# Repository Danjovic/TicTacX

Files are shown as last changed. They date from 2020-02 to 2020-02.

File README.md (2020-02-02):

# Tic Tac X

Tic Tac X is a portable color bar genarator designed to be provide the identification of VGA monitors that are able to operate with RS-170 (RGB 15.75KHz hsync).
The signals generated mimics the timing of syncrhonization pulses produced by TMS9128 (MSX1), V9938 (MSX2) and TK90X ULA (ZX Spectrum clone). A VGA mode is also provided to check the operational state of the monitor under native video signal. 

## Operation
The board provides a Jumper to turn on/off the board. As soon as the Jumper is inserted the board is powered and the VGA mode kicks in.

The board also provides a push button to change the signal mode. At every press it advances to the next mode until it returns to native (VGA) mode.

Those are the modes available:

1. VGA,  separated Hsync and Vsync 
2. NTSC, composite sync on Hsync pin
3. NTSC, separated Hsync and Vsync 
4. NTSC, sync on green
5. PAL,  composite sync on Hsync pin
6. PAL,  separated Hsync and Vsync 
7. PAL,  sync on green

All modes provide a colour bar pattern in the following sequence:

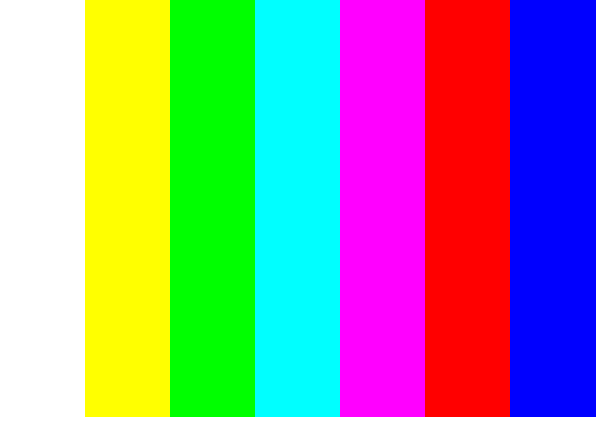
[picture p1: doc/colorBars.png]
Colour Bars


All modes, except VGA provide an horizontal bar atthe middle of the height of the screen that provides information about the mode being generated, type of synchronism signals and vertical frequency
 
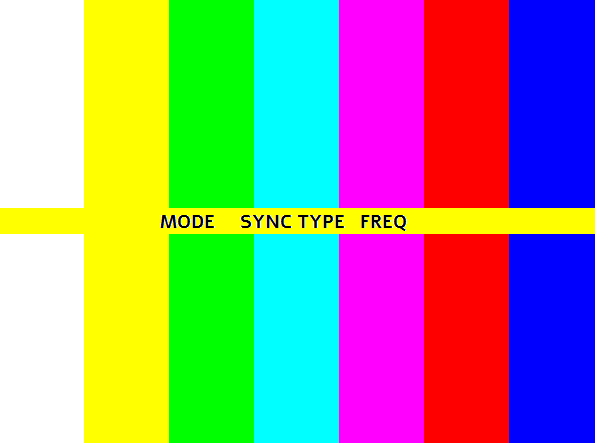
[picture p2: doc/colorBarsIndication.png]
Colour Bars and Indication


*Modes:*
* MSX1 - TMS9128 compatible, 262/313 lines progressive
* MSX2 - V9938 compatible, 525/625 lines interlaced
* TK90 - (ZX spectrum clone)

*Synchronism type:*
* CSy - Composite sync on Hsync line
* HV  - Separate Hsync and Vsync
* SoG - Sync on Green

The color of such bar relates to the type of synchronism signals
* Yellow: Composite sync
* White:  Separate Hsync
* Green:  Sync on Green

*Vertical frequency:*
* 60 - NTSC
* 50 - PAL

## Battery Saving
After 1 minute without any press of the button the board enters in sleep mode to save the battery, but when the board is not in use the on/off jumper shall be off.

## Targets
The circuit is targetted for PIC microcontrollers with at least 14 pins, capable to operate at 20MHz. The current code requires at least 4kWords of flash and is targetted for PIC16F648A and 16F688A. 

## Limitations
The source code provides support for PAL (50Hz) operation, but the current implementation only provides the NTSC (60Hz) modes. 
There are at least two ways to implement support for PAL:
* Add 6 PAL modes cycling after (or in between) the existing;
* use the solder jumper under the board to provide the PAL modes instead of the NTSC modes;
* use the solder jumper under the board to provide the extra 6 PAL modes;

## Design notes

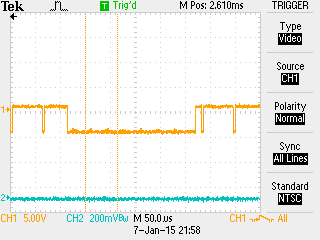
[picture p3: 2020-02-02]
doc/Waveforms/TK90X/TEK0013.TIF

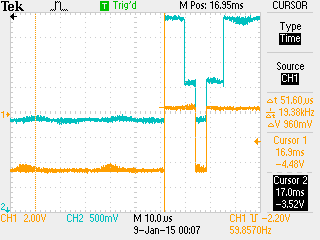
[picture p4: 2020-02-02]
doc/Waveforms/TK90X/ULA Heq2.png

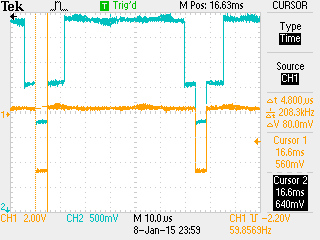
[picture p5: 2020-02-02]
doc/Waveforms/TK90X/ULA hsync time.png

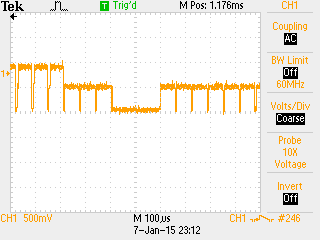
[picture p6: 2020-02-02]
doc/Waveforms/MSX/TEK0032.TIF

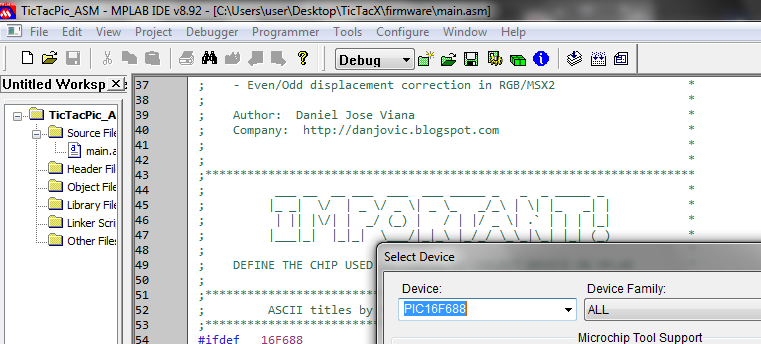
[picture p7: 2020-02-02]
doc/Selecting16F688.png

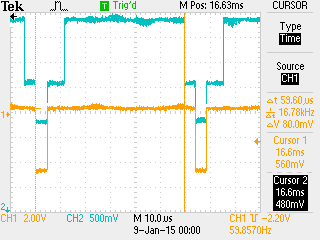
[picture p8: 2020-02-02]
doc/Waveforms/TK90X/ULA Hsync to frontporch.png

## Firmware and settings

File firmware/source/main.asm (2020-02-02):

;**********************************************************************
;            _____ _   _____          ___ ___ ___                     *
;           |_   _(_)_|_   _|_ _ __  | _ \ __|   \                    *
;             | | | / _|| |/ _` / _| |   / _|| |) |                   *
;             |_| |_\__||_|\__,_\__| |_|_\___|___/                    *
;                                                                     *
;                                                                     *
;   This program generates color bars at 15KHz horizontal frequency   *
;   in order to identify modern LCD monitors that can operate with    *  
;   80's computers like MSX and ZX Spectrum                           *
;   The video sync timing is based on TMS9918 operating manual as     *
;   well as measurements from TK90X ULA (brazilian Spectrum Clone)    *
;                                                                     *
;   The program also generates a 640x480p/60Hz signal for checking    *
;   if the monitor is working while driven by a known standard        *
;                                                                     *
;**********************************************************************
;                                                                     *
;    Filename:	    main.asm                                          *
;    Version 0.1   December 31st 2014                                 *
;    - Basic release                                                  * 
;    Version 0.2    January  8th 2015                                 *
;    - Support PIC16F628/648                                          * 
;    - Energy Saving by Biasing Red/Blue signals with PortA pins      *
;    Version 0.3    February  14th 2015                               *
;    - Bug Correction                                                 * 
;    - MSX1 Border generation correction                              *
;    Version 0.4    March     14th 2015                               *
;    - Bug Correction in Vsync levels for TK90X mode                  * 
;    Version 0.5    March     14th 2015                               *
;    - Added Graphics routines to show Machine, Sync and Freq         *
;    Version 0.6    March     24th 2015                               *
;    - Bug Correction in background color on graphics area for TK90X  *
;    Version 0.7    April      3th 2015                               *
;    - Bug Correction in RGB/MSX2 timimg                              *
;    Version 0.8    April     22th 2015                               *
;    - Even/Odd displacement correction in RGB/MSX2                   *
;                                                                     *
;    Author:  Daniel Jose Viana                                       *
;    Company:  http://danjovic.blogspot.com                           *
;                                                                     * 
;                                                                     *
;**********************************************************************
;          ___ __  __ ___  ___  ___ _____ _   _  _ _____ _            *
;         |_ _|  \/  | _ \/ _ \| _ \_   _/_\ | \| |_   _| |           *
;          | || |\/| |  _/ (_) |   / | |/ _ \| .` | | | |_|           *
;         |___|_|  |_|_|  \___/|_|_\ |_/_/ \_\_|\_| |_| (_)           *
;                                                                     *
;    DEFINE THE CHIP USED IN CONFIGURE->SELECT DEVICE ON MPLAB        *
;                                                                     *
;**********************************************************************
;         ASCII titles by http://patorjk.com/software/taag/           *
;**********************************************************************
#ifdef __16F688
;  ___ ___ ___ _  __ ___ __  ___  ___ 
; | _ \_ _/ __/ |/ /| __/ / ( _ )( _ )
; |  _/| | (__| / _ \ _/ _ \/ _ \/ _ \
; |_| |___\___|_\___/_|\___/\___/\___/
;                                     
;
	list	 p=16f688		; list directive to define processor
	#include <P16F688.inc>	; processor specific variable definitions
	__CONFIG    _CP_OFF & _CPD_OFF & _BOD_OFF & _PWRTE_ON & _WDT_OFF & _HS_OSC & _MCLRE_ON & _FCMEN_OFF & _IESO_OFF	

#define PORT_RGB PORTC
#define TRIS_RGB TRISC
#define _CMCON CMCON0

; Pins from PORT A - Board revision C, female connector
_RED_BIAS  EQU 1  
_BLUE_BIAS EQU 2
_50HZ      EQU 0  ; 50Hz Selection

; Pins from PORT C - Board revision C, female connector
_RD       EQU 0 ; Red Pin
_GR       EQU 1 ; Green Pin
_BL       EQU 3 ; Blue Pin
_SOG      EQU 2 ; Green BIAS for Sync on Green
_HSYNC    EQU 4 ; Horizontal Sync
_VSYNC    EQU 5 ; Vertical Sync

#endif 

;**********************************************************************
;#ifdef __16F628A
;  ___ ___ ___ _  __ ___ __ ___ ___   _   
; | _ \_ _/ __/ |/ /| __/ /|_  | _ ) /_\  
; |  _/| | (__| / _ \ _/ _ \/ // _ \/ _ \ 
; |_| |___\___|_\___/_|\___/___\___/_/ \_\                                        
;                                    
;    list	 p=16f628A		; list directive to define processor
;    #include <P16F628A.inc>	; processor specific variable definitions
;    __CONFIG    _CP_OFF & _CPD_OFF & _BODEN_OFF & _PWRTE_ON & _LVP_OFF & _WDT_OFF & _HS_OSC & _MCLRE_ON 

;#define PORT_RGB PORTB
;#define TRIS_RGB TRISB
;#define _CMCON CMCON

; Pins from PORT A
;_RED_BIAS  EQU 0  
;_BLUE_BIAS EQU 1
;_50HZ      EQU 4  ; 50Hz Selection

; Pins from PORT B
;_RD       EQU 0 ; Red Pin
;_GR       EQU 5 ; Green Pin
;_BL       EQU 3 ; Blue Pin
;_SOG      EQU 4 ; Green BIAS for Sync on Green
;_HSYNC    EQU 2 ; Horizontal Sync
;_VSYNC    EQU 1 ; Vertical Sync

;#endif

;**********************************************************************
#ifdef __16F648A
;  ___ ___ ___ _  __ ___ __ _ _  ___ 
; | _ \_ _/ __/ |/ /| __/ /| | |( _ )
; |  _/| | (__| / _ \ _/ _ \_  _/ _ \
; |_| |___\___|_\___/_|\___/ |_|\___/
;                                    
    list	 p=16f648A		; list directive to define processor
    #include <P16F648A.inc>	; processor specific variable definitions
    __CONFIG    _CP_OFF & _CPD_OFF & _BODEN_OFF & _PWRTE_ON & _LVP_OFF & _WDT_OFF & _HS_OSC & _MCLRE_ON 

#define PORT_RGB PORTB
#define TRIS_RGB TRISB
#define _CMCON CMCON

; Pins from PORT A
_RED_BIAS  EQU 0  
_BLUE_BIAS EQU 1
_50HZ      EQU 4  ; 50Hz Selection

; Pins from PORT B
_RD       EQU 0 ; Red Pin
_GR       EQU 5 ; Green Pin
_BL       EQU 3 ; Blue Pin
_SOG      EQU 4 ; Green BIAS for Sync on Green
_HSYNC    EQU 2 ; Horizontal Sync
_VSYNC    EQU 1 ; Vertical Sync

#endif  


;**********************************************************************
;  ___       __ _      _ _   _             
; |   \ ___ / _(_)_ _ (_) |_(_)___ _ _  ___
; | |) / -_)  _| | ' \| |  _| / _ \ ' \(_-<
; |___/\___|_| |_|_||_|_|\__|_\___/_||_/__/
;                                          
;**********************************************************************

; Macros
#define  _bank0  bcf STATUS,RP0
#define  _bank1  bsf STATUS,RP0

; Pins from PORT A
;_RED_BIAS  EQU 1  
;_BLUE_BIAS EQU 2

; Pins from PORT C
;_SOG      EQU 0
;_HSYNC    EQU 1
;_VSYNC    EQU 2
;_RD       EQU 3 ; Red Pin
;_BL       EQU 4 ; Green Pin
;_GR       EQU 5 ; Blue Pin

; VGA sync levels definition - Separate sync only
_VGA_SHELF     EQU ( (1<<_SOG) | (1<<_HSYNC) | (1<<_VSYNC) ) ; R,G,B at black, Syncs at High (inactive)
_VGA_HSYNC     EQU ( (1<<_SOG) |               (1<<_VSYNC) ) ; R,G,B at black, HSync Active (Low)
_VGA_VSHELF    EQU ( (1<<_SOG) | (1<<_HSYNC)               ) ; R,G,B at black, VSync Active (Low)
_VGA_VSYNC     EQU ( (1<<_SOG)                             ) ; R,G,B at black, HSync and VSync both Active (Low)

; RGB sync levels definition - Separate, Composite and Sync on Green
_RGBHV_HSYNC   EQU ( (1<<_SOG) |               (1<<_VSYNC) ) ; R,G,B at black, HSync Active (Low)
_RGBHV_HSHELF  EQU ( (1<<_SOG) | (1<<_HSYNC) | (1<<_VSYNC) ) ; R,G,B at black, Syncs at High (inactive)
_RGBHV_vSYNC   EQU ( (1<<_SOG)                             ) ; R,G,B at black, HSync and VSync both Active (Low)
_RGBHV_vSHELF  EQU ( (1<<_SOG) | (1<<_HSYNC)               ) ; R,G,B at black, VSync Active (Low)

_RGBCS_HSYNC   EQU ( (1<<_SOG) |               (1<<_VSYNC) ) ; R,G,B at black, HSync Active (Low)
_RGBCS_HSHELF  EQU ( (1<<_SOG) | (1<<_HSYNC) | (1<<_VSYNC) ) ; R,G,B at black, Syncs at High (inactive)
_RGBCS_vSYNC   EQU ( (1<<_SOG) |               (1<<_VSYNC) ) ; R,G,B at black, HSync and VSync both Active (Low)
_RGBCS_vSHELF  EQU ( (1<<_SOG) | (1<<_HSYNC) | (1<<_VSYNC) ) ; R,G,B at black, VSync Active (Low)

_RGBSOG_HSYNC  EQU (             (1<<_HSYNC) | (1<<_VSYNC) ) ; R,G,B at black, HSync Active (Low)
_RGBSOG_HSHELF EQU ( (1<<_SOG) | (1<<_HSYNC) | (1<<_VSYNC) ) ; R,G,B at black, Syncs at High (inactive)
_RGBSOG_vSYNC  EQU (             (1<<_HSYNC) | (1<<_VSYNC) ) ; R,G,B at black, HSync and VSync both Active (Low)
_RGBSOG_vSHELF EQU ( (1<<_SOG) | (1<<_HSYNC) | (1<<_VSYNC) ) ; R,G,B at black, VSync Active (Low)


; Colors definition - same for VGA and RGB
_WHITE       EQU ( _VGA_SHELF | (1<<_RD) |(1<<_GR) |(1<<_BL) )
_YELLOW      EQU ( _VGA_SHELF | (1<<_RD) |(1<<_GR)           )
_CYAN        EQU ( _VGA_SHELF |           (1<<_GR) |(1<<_BL) )
_GREEN       EQU ( _VGA_SHELF |           (1<<_GR)           )
_MAGENTA     EQU ( _VGA_SHELF | (1<<_RD) |          (1<<_BL) )
_RED         EQU ( _VGA_SHELF | (1<<_RD)                     )
_BLUE        EQU ( _VGA_SHELF |                     (1<<_BL) )
_BLACK       EQU ( _VGA_SHELF                                )



; Timing definitions for NTSC / PAL
_NTSC_TOP_BORDER      EQU .27
_NTSC_BOTTOM_BORDER   EQU .24 ; for MSX1 discount 1 line for checking timeout

_PAL_TOP_BORDER      EQU .57
_PAL_BOTTOM_BORDER   EQU .45 ; for MSX1 discount 1 line for checking timeout


_TK90_NTSC_TOP_BORDER      EQU .15
_TK90_NTSC_BOTTOM_BORDER   EQU .22 

_TK90_PAL_TOP_BORDER      EQU .33
_TK90_PAL_BOTTOM_BORDER   EQU .54 

 



;**********************************************************************
; __   __        _      _    _        
; \ \ / /_ _ _ _(_)__ _| |__| |___ ___
;  \ V / _` | '_| / _` | '_ \ / -_|_-<
;   \_/\__,_|_| |_\__,_|_.__/_\___/__/
;                                     
;**********************************************************************

 udata
OPMode      res 1 ; Operating mode 
Conta       res 1
Temp        res 1
GRPCOUNT    res 1 ; Graphics line counter
RGB_HSYNC   res 1 ; hold HSYNC level for RGB modes
RGB_SHELF   res 1 ; hold SHELF level for RGB modes
RGB_VSYNC   res 1 ; hold VSYNC level for RGB modes
RGB_VSHELF  res 1 ; hold VSYNC SHELF level for RGB modes
RGB_TBORDER res 1 ; hold RGB Top border counter for RGB modes
RGB_BBORDER res 1 ; hold RGB Top border counter for RGB modes
                  ; NTSC = 262 lines, top/bottom borders are 27/24 lines
                  ; PAL  = 313 lines, top/bottom borders are 57/45 lines
SLPTIMERL   res 1 ; Sleep Timer Low byte
SLPTIMERH   res 1 ; Sleep Timer High byte
SLP_TOUT    res 1 ; Sleep Timer high limit

MACHINE     res 1 ; Machine definition 0=TK90 1=MSX1 2=MSX2
FREQ        res 1 ; Vertical frequency 0=60Hz 1=50Hz
SYNCMODE    res 1 ; Sync mode 0=Sync on Green, 1=Separate Sync, 2=Composite Sync

RGB_BORDCLR res 1 ; Border Color
RGB_FGCOLOR res 1 ; Foreground Color indicator of Sync type in RGB modes
RGB_BGCOLOR res 1 ; Background Color indicator of Sync type in RGB modes

w_temp	    res 1  ; variable used for context saving
status_temp res 1  ; variable used for context saving
pclath_temp res 1  ; variable used for context saving




;**********************************************************************
;  ___ _            _             
; / __| |_ __ _ _ _| |_ _  _ _ __ 
; \__ \  _/ _` | '_|  _| || | '_ \
; |___/\__\__,_|_|  \__|\_,_| .__/
;                           |_|   
;**********************************************************************


	ORG		0x000			; processor reset vector
   	goto		main			; go to beginning of program


	ORG		0x004			; interrupt vector location
	movwf		w_temp			; save off current W register contents
	movf		STATUS,w		; move status register into W register
	movwf		status_temp		; save off contents of STATUS register
	movf		PCLATH,w		; move pclath register into W register
	movwf		pclath_temp		; save off contents of PCLATH register

; isr code can go here or be located as a call subroutine elsewhere
 
	movf		pclath_temp,w		; retrieve copy of PCLATH register
	movwf		PCLATH			; restore pre-isr PCLATH register contents	
	movf		status_temp,w		; retrieve copy of STATUS register
	movwf		STATUS			; restore pre-isr STATUS register contents
	swapf		w_temp,f
	swapf		w_temp,w		; restore pre-isr W register contents
	retfie					; return from interrupt


;**********************************************************************
;  __  __      _        ___             _   _          
; |  \/  |__ _(_)_ _   | __|  _ _ _  __| |_(_)___ _ _  
; | |\/| / _` | | ' \  | _| || | ' \/ _|  _| / _ \ ' \ 
; |_|  |_\__,_|_|_||_| |_| \_,_|_||_\__|\__|_\___/_||_|
;                                                      
;**********************************************************************

 
main

; Configure IO Ports
	bcf STATUS,RP0           ;Select Bank 0
	clrf    PORT_RGB ;C            ;Set all pins on Port C

    clrf SLPTIMERL           ; clear auto poweroff timeout variable
    clrf SLPTIMERH           ;  

    movlw   b'00000111'        
    movwf   _CMCON           ; disable analog comparators to save power


	bsf STATUS,RP0           ;Select Bank 1

	clrf    TRISA            ;Set all PortA pins as outputs 
                             
    movlw ~( 1<<_SOG | 1<<_HSYNC | 1<<_VSYNC | 1<<_RD | 1<<_BL | 1<<_GR ) 
	movwf   TRIS_RGB         ;Set all pins used for video generation as outputs

    
    movlw   b'10000000'
    movwf   VRCON              ;Turn off CVref to save power



;**********************************************************************
;  _____ ___ ___ _____   ___          _   _             
; |_   _| __/ __|_   _| | _ \___ _  _| |_(_)_ _  ___ ___
;   | | | _|\__ \ | |   |   / _ \ || |  _| | ' \/ -_|_-<
;   |_| |___|___/ |_|   |_|_\___/\_,_|\__|_|_||_\___/__/
;                                                       
;**********************************************************************
;include <test_routines.asm>

;**********************************************************************
;  __  __         _       ___      _        _   _          
; |  \/  |___  __| |___  / __| ___| |___ __| |_(_)___ _ _  
; | |\/| / _ \/ _` / -_) \__ \/ -_) / -_) _|  _| / _ \ ' \ 
; |_|  |_\___/\__,_\___| |___/\___|_\___\__|\__|_\___/_||_|
;                                                          
;**********************************************************************
   

; Choose Operating Mode
	btfsc PCON,NOT_POR       ; Check the source of reset.
	goto Select_Mode         ; If /POR  bit is set it was a button press
	                         ; otherwise initialize OPMode variable
	bsf PCON,NOT_POR         ; set /POR to indicate that this is not a POWERON Reset



FirstRun:
	bcf STATUS,RP0
	clrf OPMode              ; Mode=0 -> is VGA Mode



Select_Mode:        ; Now check which mode to operate
	bcf STATUS,RP0      ; bank 0

    movlw   _BLACK
    movwf RGB_FGCOLOR


	movf OPMode,w
	xorlw 0      
	btfsc STATUS,Z      ; Was zero?
	goto MakeMODE0      ; Yes, make first mode

	xorlw 0^1
	btfsc STATUS,Z      ; Was 1
	goto MakeMODE1      ; Yes, make 2nd mode

	xorlw 1^2
	btfsc STATUS,Z      ; Was 2
	goto MakeMODE2      ; Yes, make 3rd mode

	xorlw 2^3
	btfsc STATUS,Z      ; Was 3
	goto MakeMODE3      ; Yes, make 4th mode

 	xorlw 3^4
	btfsc STATUS,Z      ; Was 4
	goto MakeMODE4      ; Yes, make 5th mode

  	xorlw 4^5
	btfsc STATUS,Z      ; Was 5
	goto MakeMODE5      ; Yes, make 6th mode

   	xorlw 5^6
	btfsc STATUS,Z      ; Was 6
	goto MakeMODE6      ; Yes, make 7th mode 

   	xorlw 6^7
	btfsc STATUS,Z      ; Was 7
	goto MakeMODE7      ; Yes, make 8th mode 
	
	xorlw 7^8
	btfsc STATUS,Z      ; Was 8
	goto MakeMODE8      ; Yes, make 9th mode 
	
   	xorlw 8^9
	btfsc STATUS,Z      ; Was 9
	goto MakeMODE9      ; Yes, make 10th mode 
	
	goto FirstRun       ; Was none of them, consider it the first mode



;**********************************************************************
; Operating Modes
;**********************************************************************
;** MODE 0: VGA 640x480 60Hz  
MakeMODE0:
	incf OPMode,f ; Update MODE for next time
	goto DO_VGA

;** MODE 1: MSX1 NTSC Composite Sync  ******************************** 
MakeMODE1:
	incf OPMode,f ; Update MODE for next time
    call MakeRGB_CS
    call Make_MSX_NTSC   
    goto DO_MSX1
    
;** MODE 2: MSX1 NTSC Separate Sync  
MakeMODE2:
	incf OPMode,f ; Update MODE for next time
    call MakeRGB_HV
    call Make_MSX_NTSC
    goto DO_MSX1

;** MODE 3: MSX1 NTSC Sync on Green   
MakeMODE3:
	incf OPMode,f ; Update MODE for next time
    call MakeRGB_SOG
    call Make_MSX_NTSC
    goto DO_MSX1
       
;** MODE 4: MSX2 NTSC Composite Sync ********************************
MakeMODE4:
	incf OPMode,f ; Update MODE for next time
    call MakeRGB_CS
    call Make_MSX_NTSC
    goto DO_MSX2

;** MODE 5: MSX2 NTSC Separate Sync  
MakeMODE5:
	incf OPMode,f ; Update MODE for next time
    call MakeRGB_HV
    call Make_MSX_NTSC
    goto DO_MSX2
    
;** MODE 6: MSX2 Sync on Green    
MakeMODE6: 
	incf OPMode,f ; Update MODE for next time
    call MakeRGB_SOG
    call Make_MSX_NTSC
    goto DO_MSX2


;** MODE 7: TK90X NTSC Composite Sync ********************************   
MakeMODE7:
	incf OPMode,f ; Update MODE for next time
    call MakeRGB_CS
    call Make_TK90X_NTSC
    goto DO_TK90X

;** MODE 8: TK90X NTSC Separate Sync   
MakeMODE8:
	incf OPMode,f ; Update MODE for next time
    call MakeRGB_HV
    call Make_TK90X_NTSC
    goto DO_TK90X

;** MODE 9: TK90X NTSC Sync on Green   
MakeMODE9:
    clrf OPMode ; Update MODE for next time = 0 for the last mode
    call MakeRGB_SOG
    call Make_TK90X_NTSC
    goto DO_TK90X



;**********************************************************************
; Prepare Sync Modes
;**********************************************************************	
MakeRGB_CS: ; Composite Sync
	movlw _RGBCS_HSYNC
 	movwf  RGB_HSYNC

	movlw _RGBCS_HSHELF  
	movwf RGB_SHELF

	movlw _RGBCS_vSYNC
	movwf RGB_VSYNC

	movlw _RGBCS_vSHELF 
	movwf RGB_VSHELF
	
	movlw _YELLOW
	movwf RGB_BGCOLOR
	
	clrf SYNCMODE ; for graphics display routine
    return

MakeRGB_HV: ; Separate Sync
	movlw _RGBHV_HSYNC
 	movwf  RGB_HSYNC

	movlw _RGBHV_HSHELF
	movwf RGB_SHELF

	movlw _RGBHV_vSYNC
	movwf RGB_VSYNC

	movlw _RGBHV_vSHELF
	movwf RGB_VSHELF
	
	movlw _WHITE
	movwf RGB_BGCOLOR
	
	movlw .1
	movwf SYNCMODE ; for graphics display routine
    return

MakeRGB_SOG: ; Sync on Green
	movlw _RGBSOG_HSYNC
 	movwf  RGB_HSYNC

	movlw _RGBSOG_HSHELF
	movwf RGB_SHELF

	movlw _RGBSOG_vSYNC
	movwf RGB_VSYNC

	movlw _RGBSOG_vSHELF
	movwf RGB_VSHELF
	
	movlw _GREEN
	movwf RGB_BGCOLOR

	movlw .2
	movwf SYNCMODE ; for graphics display routine	
	
    return


;**********************************************************************
; Prepare Timing Modes for Top/Bottom Borders
;**********************************************************************	
Make_MSX_NTSC: ; 60Hz
	movlw _NTSC_TOP_BORDER
	movwf RGB_TBORDER

	movlw _NTSC_BOTTOM_BORDER
	movwf RGB_BBORDER

    movlw 0x0f
    movwf SLP_TOUT  ; sleep after 0f00h lines = 3840/60 s = 64 seconds
    
    clrf FREQ ; for graphics display routine
    return

Make_MSX_PAL: ; 50Hz
	movlw _PAL_TOP_BORDER
	movwf RGB_TBORDER

	movlw _PAL_BOTTOM_BORDER
	movwf RGB_BBORDER

    movlw 0x0c
    movwf SLP_TOUT  ; sleep after 0c00h lines = 3072/50 s = 61,4 seconds
    
    movlw .1
    movwf FREQ ; for graphics display routine
    return

Make_TK90X_NTSC: ;60Hz
	movlw _TK90_NTSC_TOP_BORDER
	movwf RGB_TBORDER

	movlw _TK90_NTSC_BOTTOM_BORDER
	movwf RGB_BBORDER

    movlw 0x0f
    movwf SLP_TOUT  ; sleep after 0f00h lines = 3840/60 s = 64 seconds
    
    clrf FREQ ; for graphics display routine
    return

Make_TK90X_PAL: ;50Hz
	movlw _TK90_PAL_TOP_BORDER
	movwf RGB_TBORDER

	movlw _TK90_PAL_BOTTOM_BORDER
	movwf RGB_BBORDER

    movlw 0x0c
    movwf SLP_TOUT  ; sleep after 0c00h lines = 3072/50 s = 61,4 seconds
    
    movlw .1
    movwf FREQ ; for graphics display routine       
    return



;**********************************************************************
; __   _____   _     ___          _   _             
; \ \ / / __| /_\   | _ \___ _  _| |_(_)_ _  ___ ___
;  \ V / (_ |/ _ \  |   / _ \ || |  _| | ' \/ -_|_-<
;   \_/ \___/_/ \_\ |_|_\___/\_,_|\__|_|_||_\___/__/
;                                                   
;**********************************************************************

; ** Render a VGA Frame
DO_VGA:
	movlw 2 ; Initialize amount of Vsync Lines

VGA_Frame:
	movwf Conta 
Vsync_loop:
	call Vsync_line
	movlw .33         ; amount of lines for next loop. Was placed here to 
	decfsz Conta,f   ; equalize timing of all loops that make the frame
	goto Vsync_loop  ; each loop takes exactly 8 cycles + call time
                   ; at 20Mhz we have 159 cycles per VGA line (31.8us)
VBackPorch:
	movwf Conta      ; 25lines backporch plus 8 lines top border
VBackPorch_Loop:
	call Blank_line
	movlw .240        ; first half of vilible lines
	decfsz Conta,f
	goto VBackPorch_Loop

First_half:
	movwf Conta      ; 240 lines
VFirst_Visible_Loop:
	call Visible_line
	movlw .240        ; second half of vilible lines
	decfsz Conta,f
	goto VFirst_Visible_Loop

Second_half:
	movwf Conta      ; 240 lines
VSecond_Visible_Loop:
	call Visible_line
	movlw .9       ; last 10 blank lines minus one
	decfsz Conta,f
	goto VSecond_Visible_Loop
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

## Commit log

2020-02-02 Uploaded circuit and Source code
    [Tic Tac PIC_628(e).brd, Tic Tac PIC_628(e).sch, Tic Tac PIC_688(e).brd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]
2020-02-02 Added documents folder
    [graficos.ods]
